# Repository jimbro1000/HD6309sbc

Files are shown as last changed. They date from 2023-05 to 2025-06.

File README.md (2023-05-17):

# HD6309 single board computer

This project is a somewhat hopeful and probably overly grandiose
attempt to create an expandable single board computer utilising
the Hitachi HD63C09 processor at its core (the ultimate version
of the ultimate 8-bit processor, allegedly)

## Status

The current version is built and under test. So far the board
is working with a single point of note. The reset line, when
released it not reaching a full high value. It is enough that
the processor treats it as released but I believe this is a
borderline condition which could result in spurious resets

## Architecture

The board is very, very basic and provides only clock, cpu and
memory. All other functions are handled off-board via an
expansion port

The CPU is clocked at 3MHz but each memory access is cycle is
only half of the CPU clock duration allowing the memory to be
shared by two CPUs operating at 3MHz

## Memory

The board operates in two modes, either a 50:50 split on ram
and rom, or a 64KB ram model with up to 4MB of paging (using 16k
pages, yes that's a lot of pages)

## Memory Map

### RAM/ROM model

$0000 - $7FFF - shared ram  
$8000 - $FEFF - rom  
$FF00 - $FFEF - mapped hardware registers  
$FFF0 - $FFFF - interrupt vectors  

### Paged RAM model (requires memory board)

$0000 - $7FFF - shared ram  
$8000 - $BFFF - paged ram  
$C000 - $FFEF - private ram  
$FF00 - $FFEF - mapped hardware registers  
$FFF0 - $FFFF - interrupt vectors  

## Hardware registers

The switching of memory models is handled by writing to bit 0
of address $FF24. Writing a low bit sets the map to RAM/ROM,
writing a high bit sets the map to paged RAM

Bits 1 to 7 are unused by default but are exposed over the
expansion bus to provide switching to other devices

For future use all addresses from $FF00 to $FFEF are reserved
for memory mapped registers. The "MAPPED_MEM" line (pin 27) on
the expansion bus is high for all addresses in this range. This
should help to keep logic on expansion boards down where a new
register is added

For expansion purposes the following addresses are fixed and
should not be reused:

$FF00:$FF03 - PIA 1
$FF04:$FF07 - PIA 2
$FF08:$FF0B - PIA 3
$FF0C:$FF0F - ACIA
$FF10:$FF1F - Video Co-Pro registers
$FF24       - Hardware enable lines (Q0 = memory model, Q1-Q7 unused)
$FF25:$FF27 - reserved for additional enable lines
$FF40:$FF48 - Floppy Disc Controller
$FF50:$FF5F - Hard Drive / MMC Controller

## Expansion port

The processor board exposes all of the CPU and timing control
lines over a 60 pin IO port to allow other devices to interface
with the processor

Intended components are audio output, video co-processor,
general peripheral IO and (slow) serial IO

## Associated designs

* Backplane <https://github.com/jimbro1000/SBCBackplane>
* Memory Board <https://github.com/jimbro1000/SBCMemoryBoard>
* Peripheral Adapter <https://github.com/jimbro1000/PIA-Module>
* VGA Board <https://github.com/jimbro1000/PicoVideoModule>
* 6847Pi <https://github.com/jimbro1000/6847Pi>
* ACIA Board <https://github.com/jimbro1000/ACIA-Module>

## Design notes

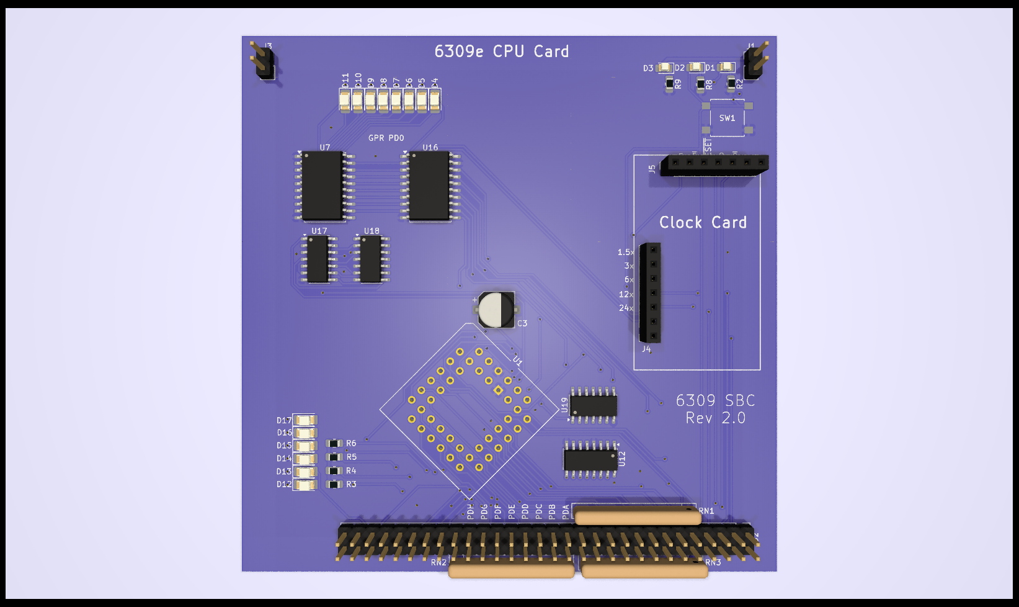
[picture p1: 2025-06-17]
HD6309sbc.png

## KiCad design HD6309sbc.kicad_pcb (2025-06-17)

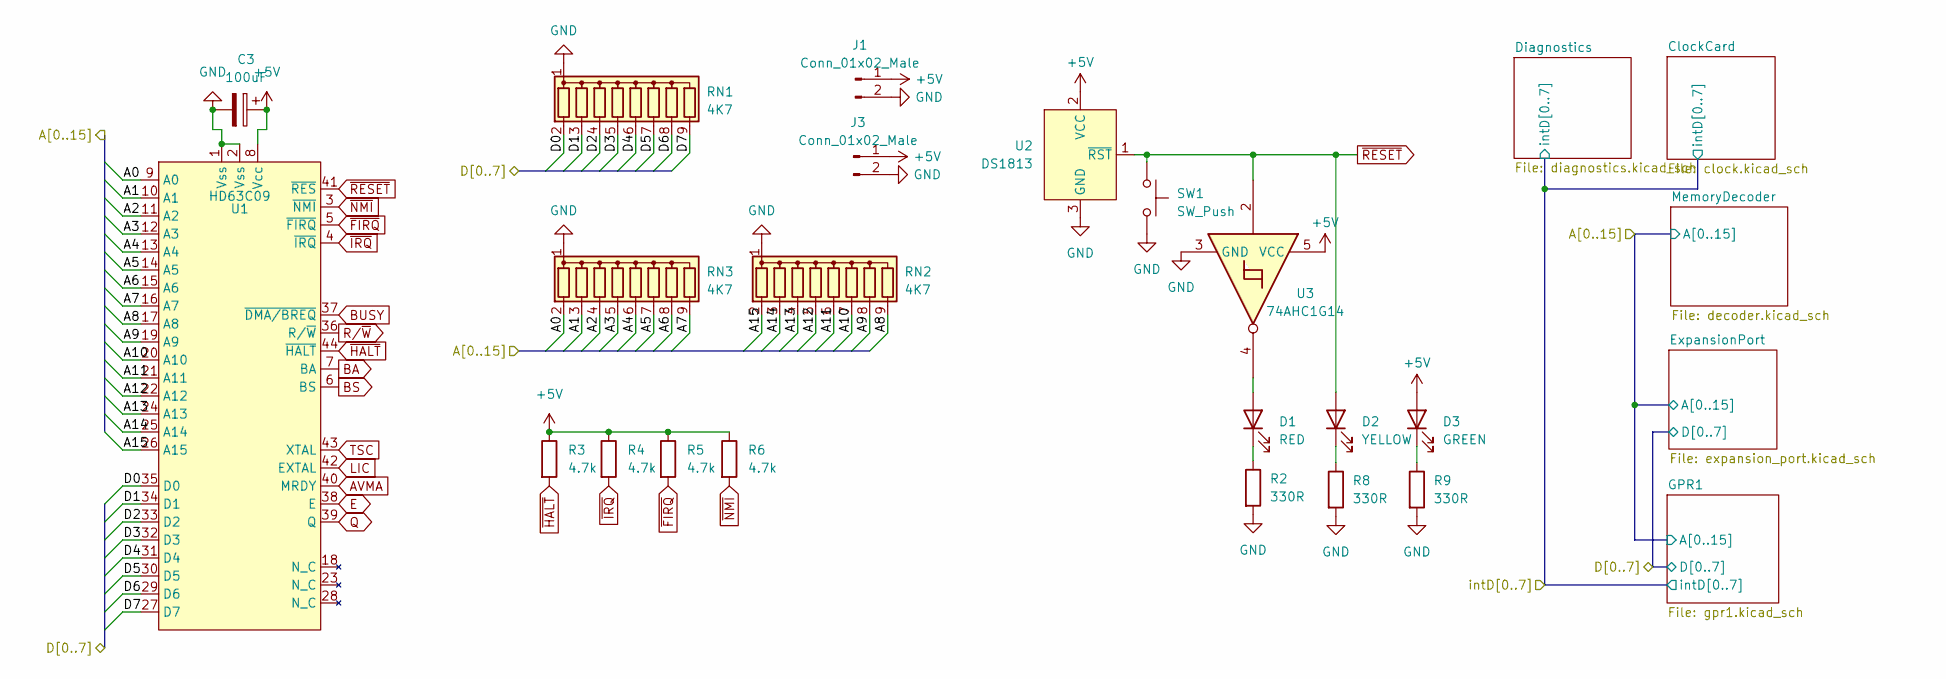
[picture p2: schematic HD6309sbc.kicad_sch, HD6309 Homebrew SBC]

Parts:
C3: 100uF; CP_Elec_6.3x5.8
D1: RED; LED_0805_2012Metric_Pad1.15x1.40mm_HandSolder
D2: YELLOW; LED_0805_2012Metric_Pad1.15x1.40mm_HandSolder
D3: GREEN; LED_0805_2012Metric_Pad1.15x1.40mm_HandSolder
J1, J3: Conn_01x02_Male; PinHeader_1x02_P2.54mm_Vertical
R2, R8, R9: 330R; R_0805_2012Metric_Pad1.20x1.40mm_HandSolder; DigiKey 2019-RK73H2ATTD2201FCT-ND
R3, R4, R5, R6: 4.7k; R_0805_2012Metric_Pad1.20x1.40mm_HandSolder; DigiKey 2019-RK73H2ATTD2201FCT-ND
RN1, RN2, RN3: 4K7; R_Array_SIP9
SW1: SW_Push; SW_SPST_B3S-1000
U1: HD63C09; PLCC-44_THT-Socket
U2: DS1813; SOT-23-3
U3: 74AHC1G14; SOT-353_SC-70-5_Handsoldering

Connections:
+5V: C3.1, D3.2 (A), J1.1, J3.1, R3.1, R4.1, R5.1, R6.1, U1.8 (Vcc), U2.2 (VCC), U3.5 (VCC); also elsewhere on the board
/A0: RN3.2 (R1), U1.9 (A0); also elsewhere on the board
/A1: RN3.3 (R2), U1.10 (A1); also elsewhere on the board
/A2: RN3.4 (R3), U1.11 (A2); also elsewhere on the board
/A3: RN3.5 (R4), U1.12 (A3); also elsewhere on the board
/A4: RN3.6 (R5), U1.13 (A4); also elsewhere on the board
/A5: RN3.7 (R6), U1.14 (A5); also elsewhere on the board
/A6: RN3.8 (R7), U1.15 (A6); also elsewhere on the board
/A7: RN3.9 (R8), U1.16 (A7); also elsewhere on the board
/A8: RN2.9 (R8), U1.17 (A8); also elsewhere on the board
/A9: RN2.8 (R7), U1.19 (A9); also elsewhere on the board
/A10: RN2.7 (R6), U1.20 (A10); also elsewhere on the board
/A11: RN2.6 (R5), U1.21 (A11); also elsewhere on the board
/A12: RN2.5 (R4), U1.22 (A12); also elsewhere on the board
/A13: RN2.4 (R3), U1.24 (A13); also elsewhere on the board
/A14: RN2.3 (R2), U1.25 (A14); also elsewhere on the board
/A15: RN2.2 (R1), U1.26 (A15); also elsewhere on the board
/D0: RN1.2 (R1), U1.35 (D0); also elsewhere on the board
/D1: RN1.3 (R2), U1.34 (D1); also elsewhere on the board
/D2: RN1.4 (R3), U1.33 (D2); also elsewhere on the board
/D3: RN1.5 (R4), U1.32 (D3); also elsewhere on the board
/D4: RN1.6 (R5), U1.31 (D4); also elsewhere on the board
/D5: RN1.7 (R6), U1.30 (D5); also elsewhere on the board
/D6: RN1.8 (R7), U1.29 (D6); also elsewhere on the board
/D7: RN1.9 (R8), U1.27 (D7); also elsewhere on the board
AVMA: U1.40 (MRDY); also elsewhere on the board
BA: U1.7 (BA); also elsewhere on the board
BS: U1.6 (BS); also elsewhere on the board
BUSY: U1.37 (~DMA/BREQ); also elsewhere on the board
E: U1.38 (E); also elsewhere on the board
GND: C3.2, J1.2, J3.2, R2.2, R8.2, R9.2, RN1.1 (common), RN2.1 (common), RN3.1 (common), SW1.2, U1.1 (Vss), U1.2 (Vss), U2.3 (GND), U3.3 (GND); also elsewhere on the board
LIC: U1.42 (EXTAL); also elsewhere on the board
unnamed: D1.2 (A), U3.4
unnamed: D1.1 (K), R2.1
unnamed: D2.1 (K), R8.1
unnamed: D3.1 (K), R9.1
Q: U1.39 (Q); also elsewhere on the board
R/~W: U1.36 (R/~W); also elsewhere on the board
TSC: U1.43 (XTAL); also elsewhere on the board
~FIRQ: R5.2, U1.5 (~FIRQ); also elsewhere on the board
~HALT: R3.2, U1.44 (~HALT); also elsewhere on the board
~IRQ: R4.2, U1.4 (~IRQ); also elsewhere on the board
~NMI: R6.2, U1.3 (~NMI); also elsewhere on the board
~RESET: D2.2 (A), SW1.1, U1.41 (~RES), U2.1 (~RST), U3.2; also elsewhere on the board

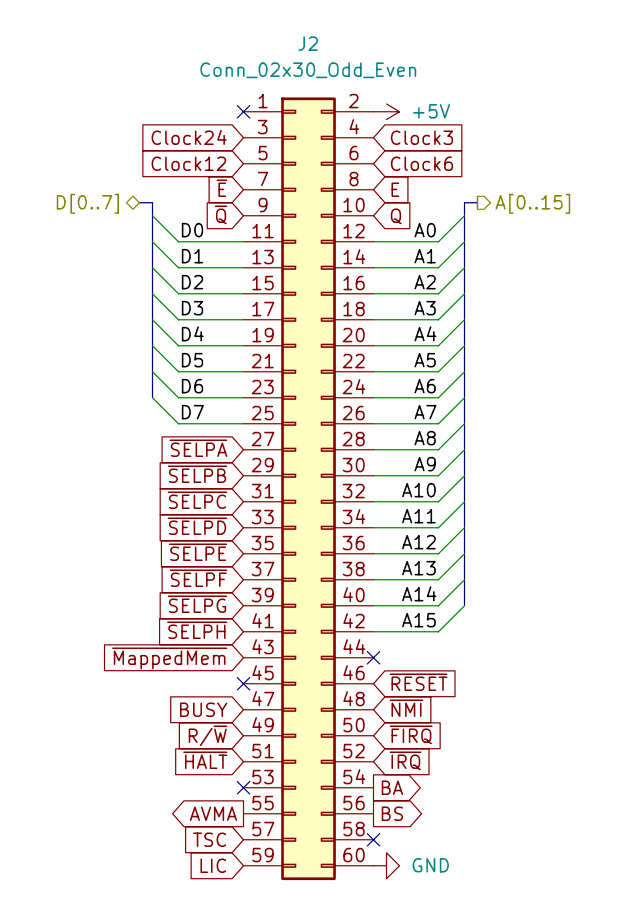
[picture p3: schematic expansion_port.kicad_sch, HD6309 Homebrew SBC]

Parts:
J2: Conn_02x30_Odd_Even; PinHeader_2x30_P2.54mm_Vertical

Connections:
+5V: J2.2; also elsewhere on the board
/A0: J2.12; also elsewhere on the board
/A1: J2.14; also elsewhere on the board
/A2: J2.16; also elsewhere on the board
/A3: J2.18; also elsewhere on the board
/A4: J2.20; also elsewhere on the board
/A5: J2.22; also elsewhere on the board
/A6: J2.24; also elsewhere on the board
/A7: J2.26; also elsewhere on the board
/A8: J2.28; also elsewhere on the board
/A9: J2.30; also elsewhere on the board
/A10: J2.32; also elsewhere on the board
/A11: J2.34; also elsewhere on the board
/A12: J2.36; also elsewhere on the board
/A13: J2.38; also elsewhere on the board
/A14: J2.40; also elsewhere on the board
/A15: J2.42; also elsewhere on the board
/D0: J2.11; also elsewhere on the board
/D1: J2.13; also elsewhere on the board
/D2: J2.15; also elsewhere on the board
/D3: J2.17; also elsewhere on the board
/D4: J2.19; also elsewhere on the board
/D5: J2.21; also elsewhere on the board
/D6: J2.23; also elsewhere on the board
/D7: J2.25; also elsewhere on the board
AVMA: J2.55; also elsewhere on the board
BA: J2.54; also elsewhere on the board
BS: J2.56; also elsewhere on the board
BUSY: J2.47; also elsewhere on the board
Clock3: J2.4; also elsewhere on the board
Clock6: J2.6; also elsewhere on the board
Clock12: J2.5; also elsewhere on the board
Clock24: J2.3; also elsewhere on the board
E: J2.8; also elsewhere on the board
GND: J2.60; also elsewhere on the board
LIC: J2.59; also elsewhere on the board
Q: J2.10; also elsewhere on the board
R/~W: J2.49; also elsewhere on the board
TSC: J2.57; also elsewhere on the board
~E: J2.7; also elsewhere on the board
~FIRQ: J2.50; also elsewhere on the board
~HALT: J2.51; also elsewhere on the board
~IRQ: J2.52; also elsewhere on the board
~MappedMem: J2.43; also elsewhere on the board
~NMI: J2.48; also elsewhere on the board
~Q: J2.9; also elsewhere on the board
~RESET: J2.46; also elsewhere on the board
~SELPA: J2.27; also elsewhere on the board
~SELPB: J2.29; also elsewhere on the board
~SELPC: J2.31; also elsewhere on the board
~SELPD: J2.33; also elsewhere on the board
~SELPE: J2.35; also elsewhere on the board
~SELPF: J2.37; also elsewhere on the board
~SELPG: J2.39; also elsewhere on the board
~SELPH: J2.41; also elsewhere on the board

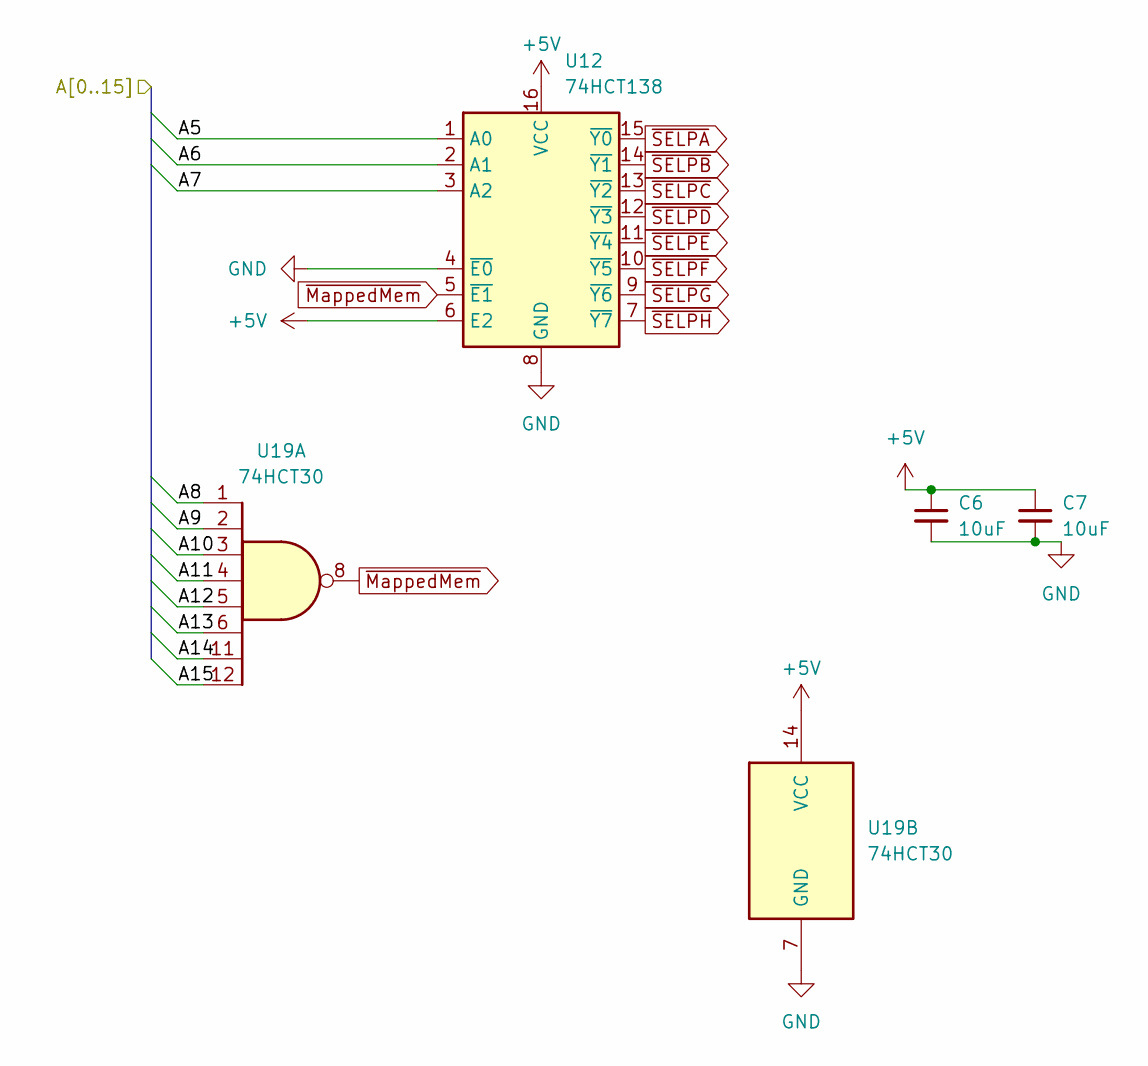
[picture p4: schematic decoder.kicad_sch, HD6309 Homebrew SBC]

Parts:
C6, C7: 10uF; C_0805_2012Metric_Pad1.18x1.45mm_HandSolder
U12: 74HCT138; SOIC-16_3.9x9.9mm_P1.27mm
U19: 74HCT30; SOIC-14_3.9x8.7mm_P1.27mm

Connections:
+5V: C6.1, C7.1, U12.6 (E2), U12.16 (VCC), U19.14 (VCC); also elsewhere on the board
/A5: U12.1 (A0); also elsewhere on the board
/A6: U12.2 (A1); also elsewhere on the board
/A7: U12.3 (A2); also elsewhere on the board
/A8: U19.1; also elsewhere on the board
/A9: U19.2; also elsewhere on the board
/A10: U19.3; also elsewhere on the board
/A11: U19.4; also elsewhere on the board
/A12: U19.5; also elsewhere on the board
/A13: U19.6; also elsewhere on the board
/A14: U19.11; also elsewhere on the board
/A15: U19.12; also elsewhere on the board
GND: C6.2, C7.2, U12.4 (~E0), U12.8 (GND), U19.7 (GND); also elsewhere on the board
~MappedMem: U12.5 (~E1), U19.8; also elsewhere on the board
~SELPA: U12.15 (~Y0); also elsewhere on the board
~SELPB: U12.14 (~Y1); also elsewhere on the board
~SELPC: U12.13 (~Y2); also elsewhere on the board
~SELPD: U12.12 (~Y3); also elsewhere on the board
~SELPE: U12.11 (~Y4); also elsewhere on the board
~SELPF: U12.10 (~Y5); also elsewhere on the board
~SELPG: U12.9 (~Y6); also elsewhere on the board
~SELPH: U12.7 (~Y7); also elsewhere on the board

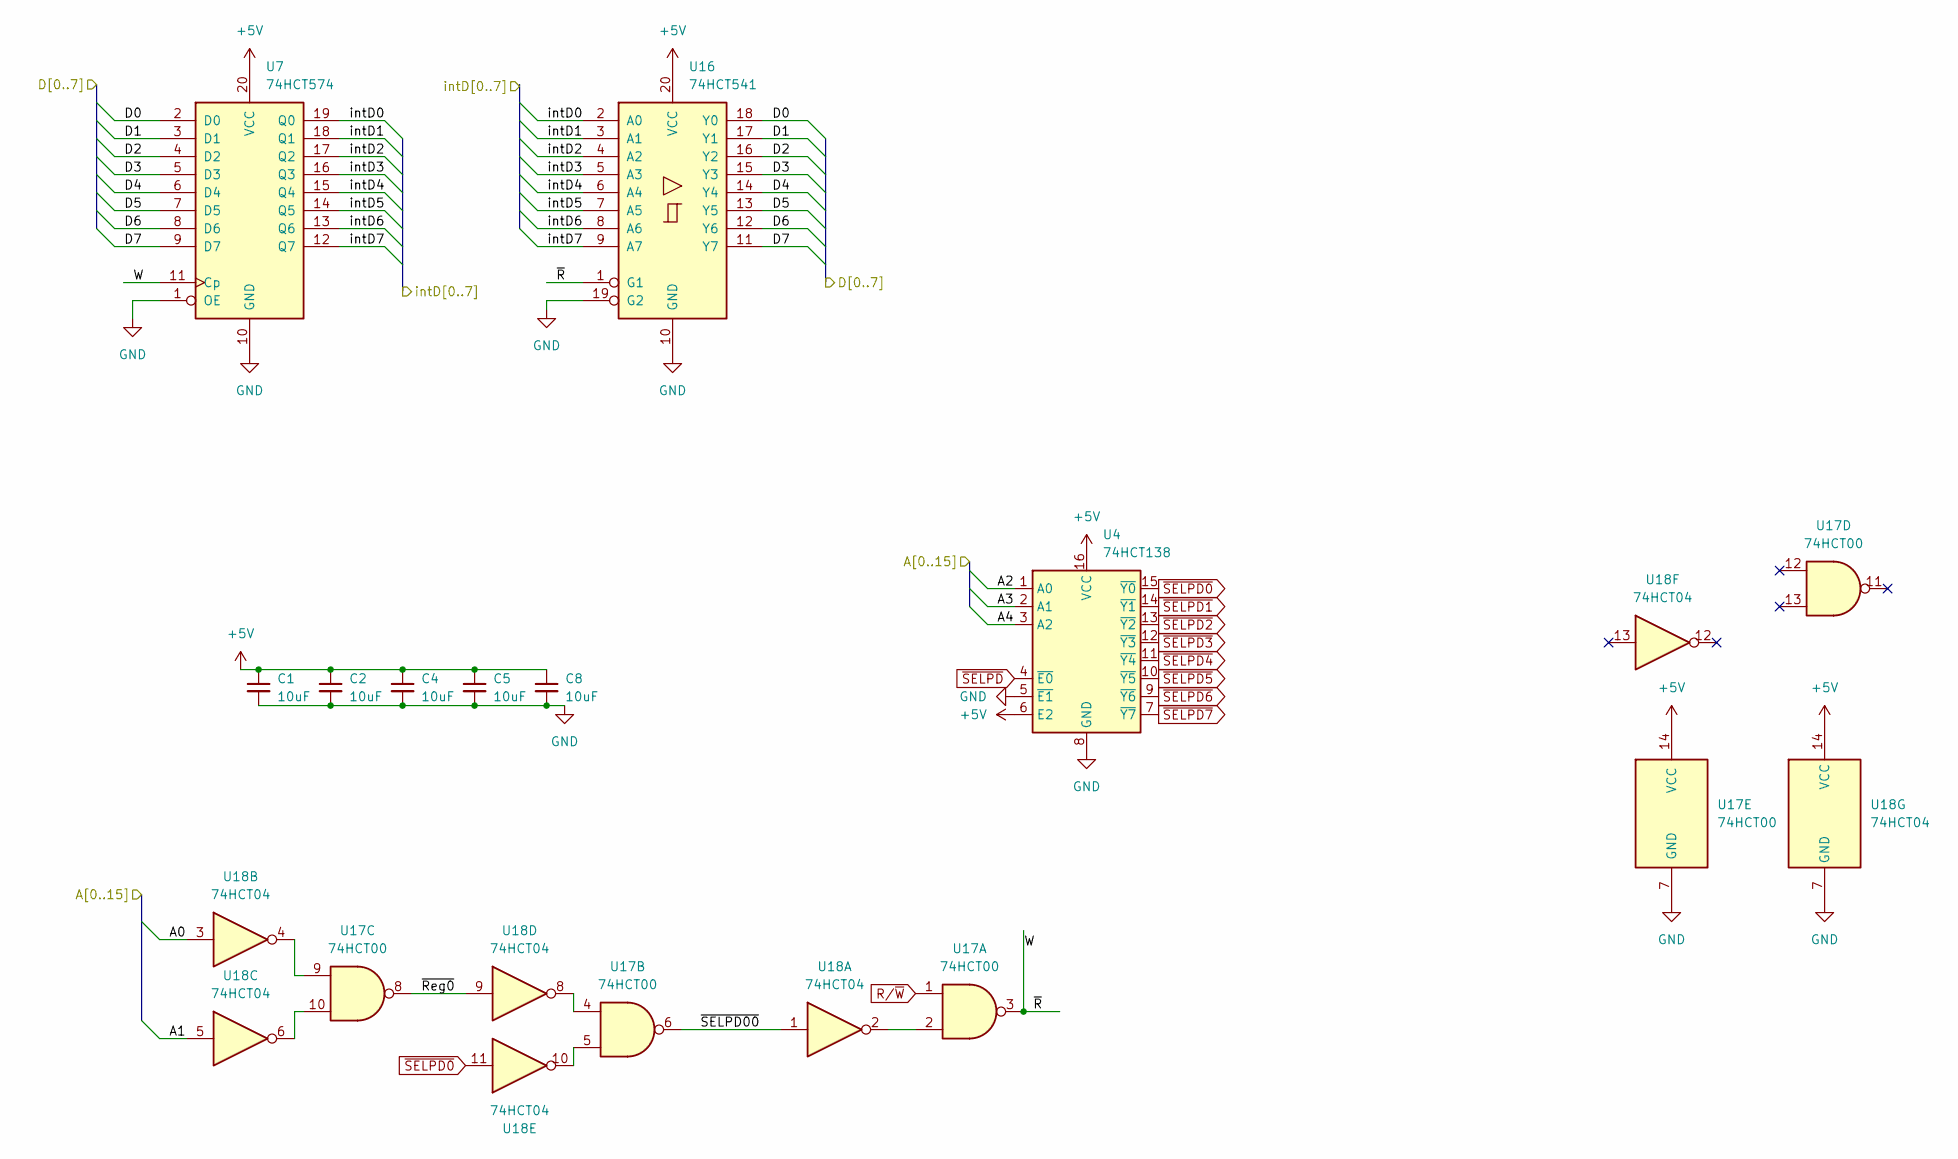
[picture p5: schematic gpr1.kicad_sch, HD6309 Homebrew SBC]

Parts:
C1, C2, C4, C5, C8: 10uF; C_0805_2012Metric_Pad1.18x1.45mm_HandSolder
U4: 74HCT138; SOIC-16_3.9x9.9mm_P1.27mm
U7: 74HCT574; SOIC-20W_7.5x12.8mm_P1.27mm; DigiKey 296-14871-1-ND
U16: 74HCT541; SOIC-20W_7.5x12.8mm_P1.27mm; DigiKey 74HCT541DCT-ND
U17: 74HCT00; SOIC-14_3.9x8.7mm_P1.27mm
U18: 74HCT04; SOIC-14_3.9x8.7mm_P1.27mm

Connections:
+5V: C1.1, C2.1, C4.1, C5.1, C8.1, U4.6 (E2), U4.16 (VCC), U7.20 (VCC), U16.20 (VCC), U17.14 (VCC), U18.14 (VCC); also elsewhere on the board
/A0: U18.3; also elsewhere on the board
/A1: U18.5; also elsewhere on the board
/A2: U4.1 (A0); also elsewhere on the board
/A3: U4.2 (A1); also elsewhere on the board
/A4: U4.3 (A2); also elsewhere on the board
/D0: U7.2 (D0), U16.18 (Y0); also elsewhere on the board
/D1: U7.3 (D1), U16.17 (Y1); also elsewhere on the board
/D2: U7.4 (D2), U16.16 (Y2); also elsewhere on the board
/D3: U7.5 (D3), U16.15 (Y3); also elsewhere on the board
/D4: U7.6 (D4), U16.14 (Y4); also elsewhere on the board
/D5: U7.7 (D5), U16.13 (Y5); also elsewhere on the board
/D6: U7.8 (D6), U16.12 (Y6); also elsewhere on the board
/D7: U7.9 (D7), U16.11 (Y7); also elsewhere on the board
/GPR1/W: U7.11 (Cp), U16.1 (G1), U17.3
/GPR1/~Reg0: U17.8, U18.9
/GPR1/~SELPD00: U17.6, U18.1
/intD0: U7.19 (Q0), U16.2 (A0); also elsewhere on the board
/intD1: U7.18 (Q1), U16.3 (A1); also elsewhere on the board
/intD2: U7.17 (Q2), U16.4 (A2); also elsewhere on the board
/intD3: U7.16 (Q3), U16.5 (A3); also elsewhere on the board
/intD4: U7.15 (Q4), U16.6 (A4); also elsewhere on the board
/intD5: U7.14 (Q5), U16.7 (A5); also elsewhere on the board
/intD6: U7.13 (Q6), U16.8 (A6); also elsewhere on the board
/intD7: U7.12 (Q7), U16.9 (A7); also elsewhere on the board
GND: C1.2, C2.2, C4.2, C5.2, C8.2, U4.5 (~E1), U4.8 (GND), U7.1 (OE), U7.10 (GND), U16.10 (GND), U16.19 (G2), U17.7 (GND), U18.7 (GND); also elsewhere on the board
unnamed: U17.2, U18.2
unnamed: U17.4, U18.8
unnamed: U17.5, U18.10
unnamed: U17.9, U18.4
unnamed: U17.10, U18.6
R/~W: U17.1; also elsewhere on the board
~SELPD0: U4.15 (~Y0), U18.11
~SELPD: U4.4 (~E0); also elsewhere on the board

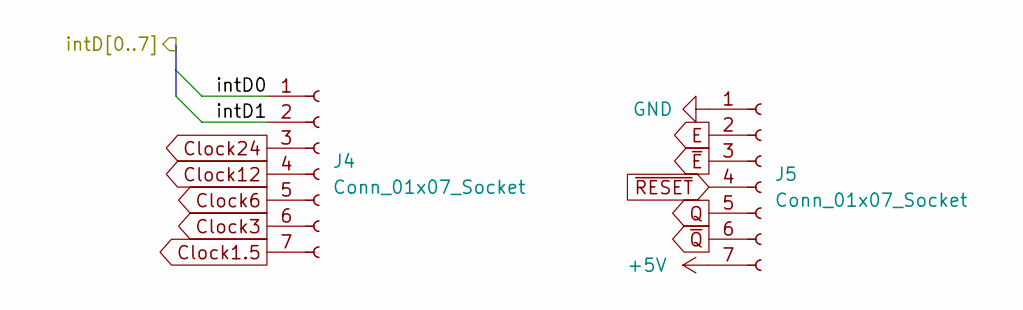
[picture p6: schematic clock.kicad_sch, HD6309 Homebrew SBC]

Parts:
J4, J5: Conn_01x07_Socket; PinSocket_1x07_P2.54mm_Vertical

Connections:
+5V: J5.7; also elsewhere on the board
/intD0: J4.1; also elsewhere on the board
/intD1: J4.2; also elsewhere on the board
Clock1.5: J4.7
Clock3: J4.6; also elsewhere on the board
Clock6: J4.5; also elsewhere on the board
Clock12: J4.4; also elsewhere on the board
Clock24: J4.3; also elsewhere on the board
E: J5.2; also elsewhere on the board
GND: J5.1; also elsewhere on the board
Q: J5.5; also elsewhere on the board
~E: J5.3; also elsewhere on the board
~Q: J5.6; also elsewhere on the board
~RESET: J5.4; also elsewhere on the board

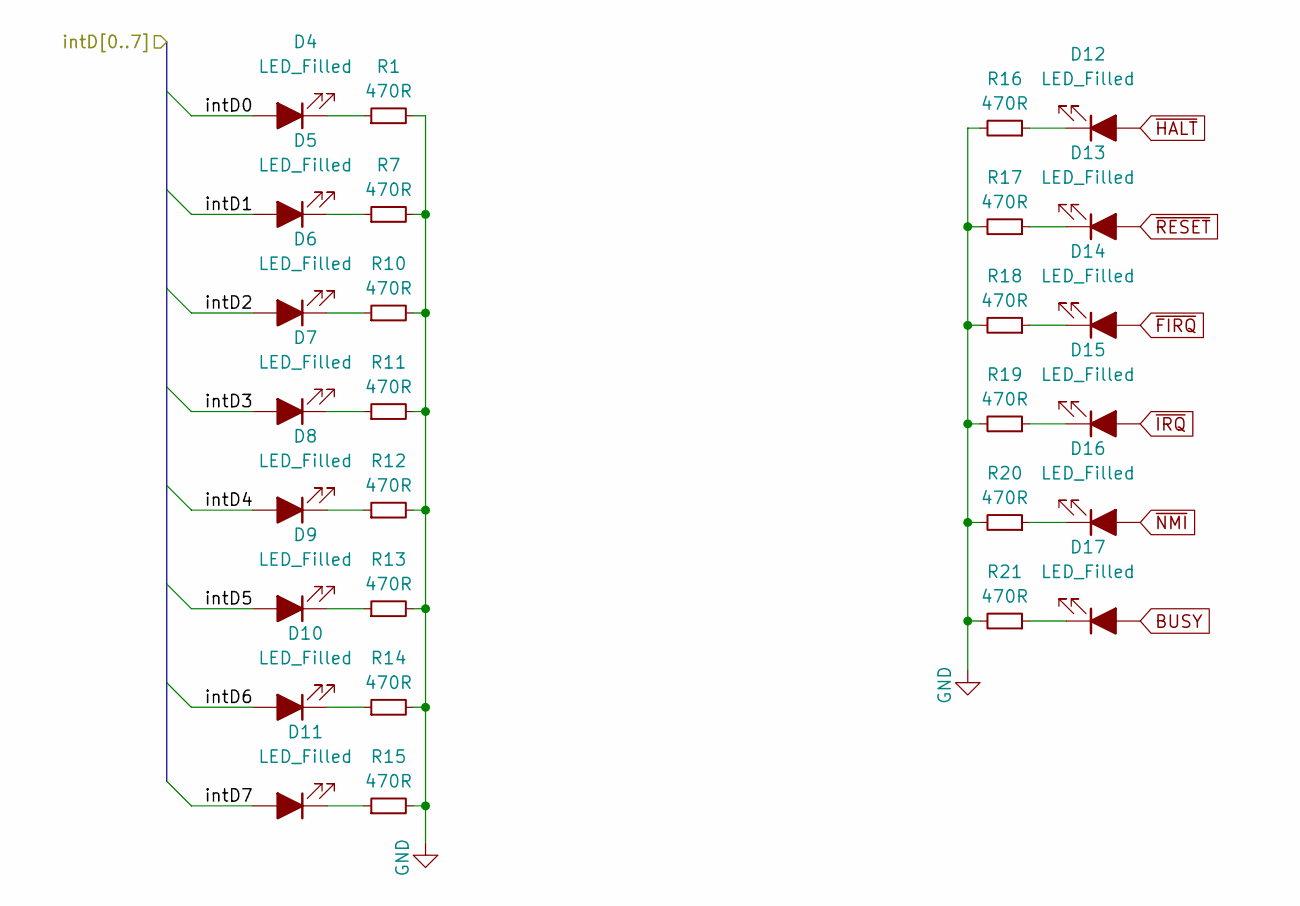
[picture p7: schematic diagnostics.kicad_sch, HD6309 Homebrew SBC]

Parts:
D4, D5, D6, D7, D8, D9, D10, D11, D12, D13, D14, D15, D16, D17: LED_Filled; LED_1206_3216Metric_Pad1.42x1.75mm_HandSolder
R1, R7, R10, R11, R12, R13, R14, R15, R16, R17, R18, R19, R20, R21: 470R; R_0805_2012Metric_Pad1.20x1.40mm_HandSolder

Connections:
/intD0: D4.2 (A); also elsewhere on the board
/intD1: D5.2 (A); also elsewhere on the board
/intD2: D6.2 (A); also elsewhere on the board
/intD3: D7.2 (A); also elsewhere on the board
/intD4: D8.2 (A); also elsewhere on the board
/intD5: D9.2 (A); also elsewhere on the board
/intD6: D10.2 (A); also elsewhere on the board
/intD7: D11.2 (A); also elsewhere on the board
BUSY: D17.2 (A); also elsewhere on the board
GND: R1.2, R7.2, R10.2, R11.2, R12.2, R13.2, R14.2, R15.2, R16.2, R17.2, R18.2, R19.2, R20.2, R21.2; also elsewhere on the board
unnamed: D4.1 (K), R1.1
unnamed: D5.1 (K), R7.1
unnamed: D6.1 (K), R10.1
unnamed: D7.1 (K), R11.1
unnamed: D8.1 (K), R12.1
unnamed: D9.1 (K), R13.1
unnamed: D10.1 (K), R14.1
unnamed: D11.1 (K), R15.1
unnamed: D12.1 (K), R16.1
unnamed: D13.1 (K), R17.1
unnamed: D14.1 (K), R18.1
unnamed: D15.1 (K), R19.1
unnamed: D16.1 (K), R20.1
unnamed: D17.1 (K), R21.1
~FIRQ: D14.2 (A); also elsewhere on the board
~HALT: D12.2 (A); also elsewhere on the board
~IRQ: D15.2 (A); also elsewhere on the board
~NMI: D16.2 (A); also elsewhere on the board
~RESET: D13.2 (A); also elsewhere on the board

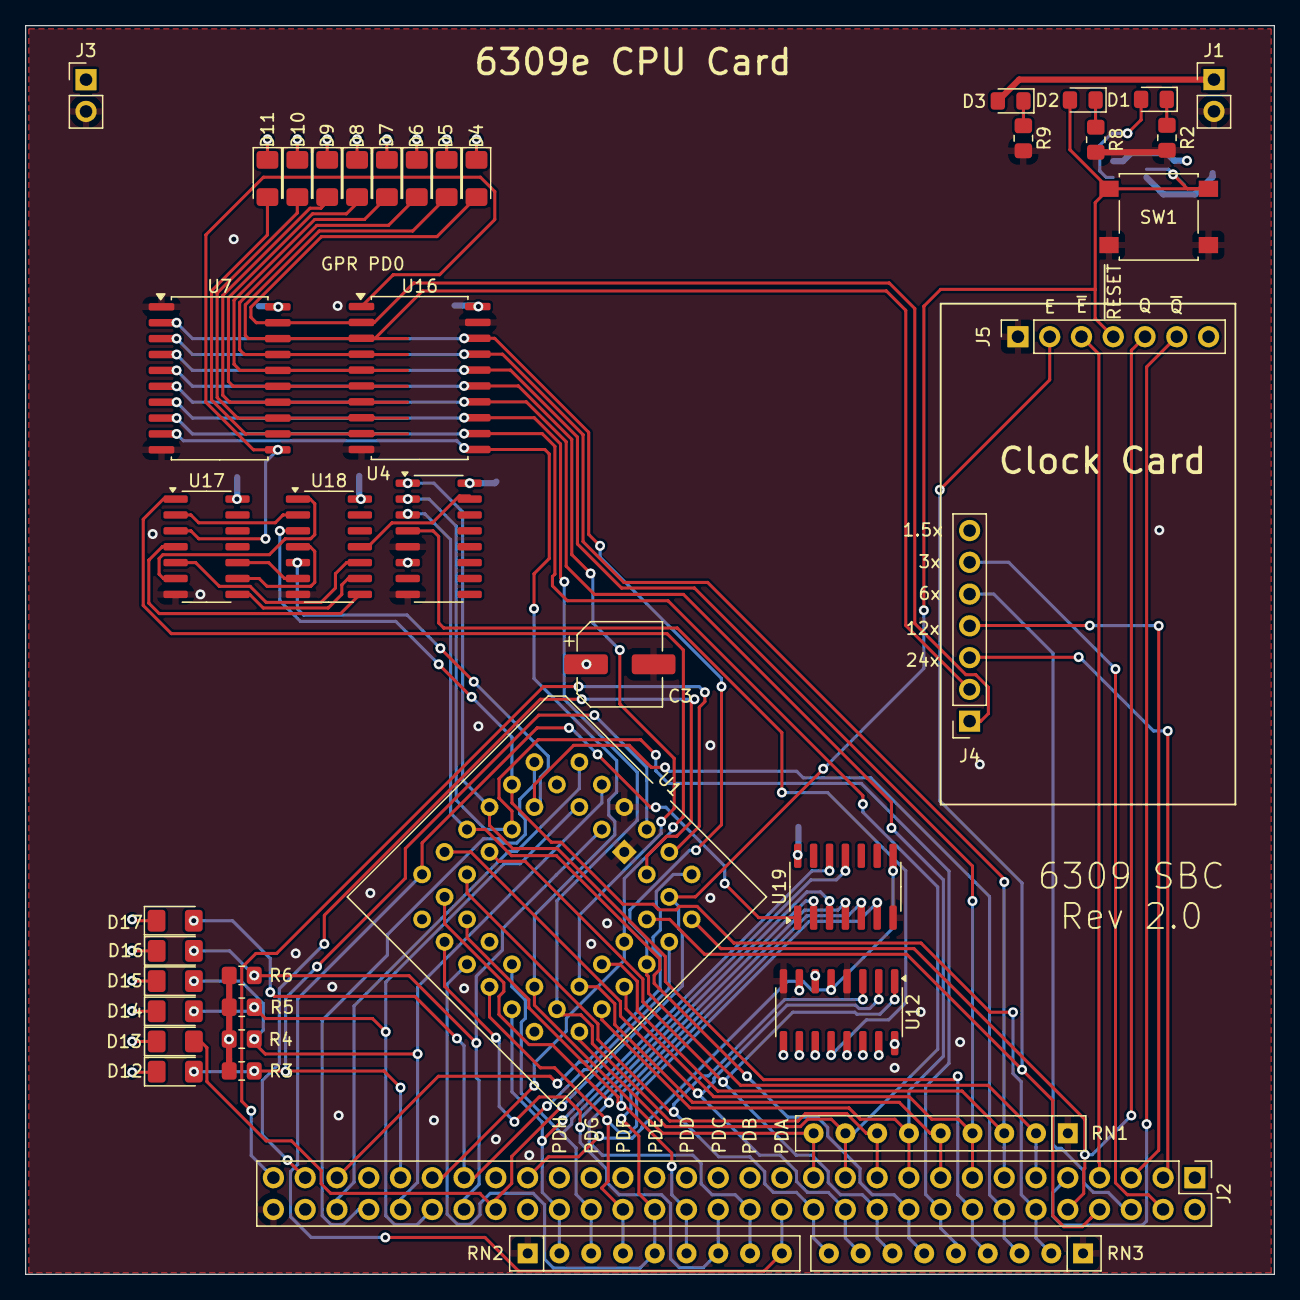
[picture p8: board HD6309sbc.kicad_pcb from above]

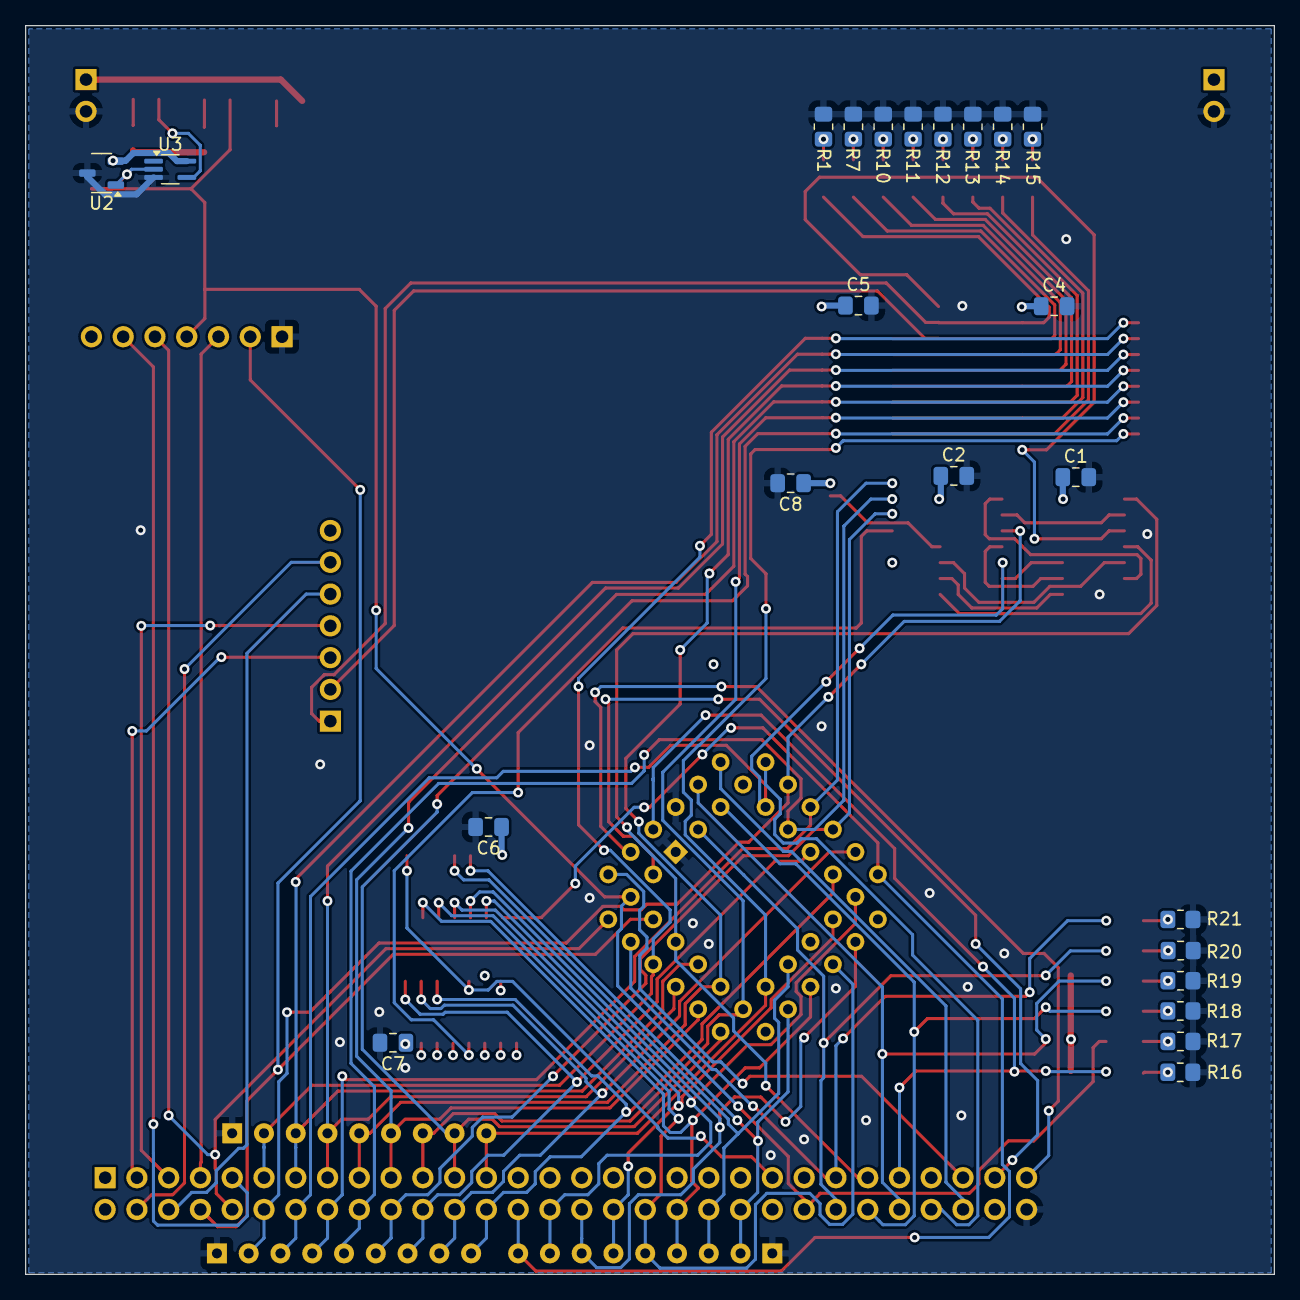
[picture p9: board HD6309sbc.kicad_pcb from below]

Board: 4 copper layers, 99.8 x 99.8 mm, 65 parts (23 on the bottom side), 90 nets.

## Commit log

2022-10-04 add paged memory
    [HD6309sbc.kicad_pcb, HD6309sbc.kicad_sch, clock.kicad_sch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]
2022-10-05 add power routing
    [HD6309sbc.kicad_pcb, HD6309sbc.kicad_sch, clock.kicad_sch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]
2022-10-05 move rom for clearance
    [HD6309sbc.dsn, HD6309sbc.kicad_pcb]
2022-10-05 rearrange components for routing
    [HD6309sbc.dsn, HD6309sbc.kicad_pcb, HD6309sbc.kicad_sch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]
2022-10-05 reduce component count
    [HD6309sbc.dsn, HD6309sbc.kicad_pcb, HD6309sbc.kicad_sch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]
2022-10-05 correct memory page addressing
    [HD6309sbc.kicad_sch, control_register_1.kicad_sch, expansion_port.kicad_sch]
2022-10-06 move paged memory to external board
    [HD6309sbc.dsn, HD6309sbc.kicad_pcb, HD6309sbc.kicad_sch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]
2022-10-06 add bom
    [HD6309sbc.kicad_sch]
2022-10-08 modify address logic for mapped registers
    [HD6309sbc.dsn, HD6309sbc.kicad_pcb, HD6309sbc.kicad_sch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]
2022-11-06 generate production
    [HD6309sbc.kicad_pcb]
2023-01-27 set reset cap value
    [HD6309sbc.kicad_sch]
2023-01-27 rework traces
    [HD6309sbc.kicad_pcb, HD6309sbc.kicad_sch, clock.kicad_sch]
2023-02-01 use handsolder pads
    [HD6309sbc.kicad_pcb, HD6309sbc.kicad_sch, clock.kicad_sch]
2023-02-01 improve keepout around crystal
    [HD6309sbc.kicad_pcb]
2023-02-16 convert to discrete clock
    [HD6309sbc.kicad_pcb, HD6309sbc.kicad_sch, clock.kicad_sch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]
2023-02-23 add diagnostics port
    [HD6309sbc.kicad_pcb, HD6309sbc.kicad_sch, diagnostics.kicad_sch]
2023-02-23 use 10 segment led bar
    [HD6309sbc.kicad_pcb, diagnostics.kicad_sch]
2023-02-24 tidy up component placing
    [HD6309sbc.kicad_pcb, HD6309sbc.kicad_sch, diagnostics.kicad_sch]
2023-03-07 fix rom footprint
    [HD6309sbc.kicad_pcb, HD6309sbc.kicad_sch]
2023-03-07 update interactive bom
2023-04-08 shorthand batch file for assembly
2023-04-11 board refresh
    [HD6309sbc.kicad_pcb, HD6309sbc.kicad_sch, diagnostics.kicad_sch]
2023-04-11 extend testkit1 with interrupt and page handling
2023-05-17 Refine reset circuit
    [HD6309sbc.kicad_pcb, HD6309sbc.kicad_sch, control_register_1.kicad_sch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]
2024-04-11 convert to new format
    [HD6309sbc.kicad_pcb, HD6309sbc.kicad_sch, clock.kicad_sch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]
2024-04-11 disambiguate register address
    [HD6309sbc.kicad_pcb, decoder.kicad_sch, diagnostics.kicad_sch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]
2024-04-15 tighten up tracing
    [HD6309sbc.kicad_pcb, gpr1.kicad_sch]
